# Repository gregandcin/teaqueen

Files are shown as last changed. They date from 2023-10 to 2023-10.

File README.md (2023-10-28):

# TeaQueen
An Alice Inspired Split Keyboard

## About the TeaQueen

The TeaQueen is a split, Alice keyboard running QMK firmware, with VIA and Vial compatibility (firmware to be realeased later). Based off of the [Red Queen](https://github.com/dbostian/redqueen) by [Dan Bostian](https://github.com/dbostian). 

V1 of the board, aka the Scuffed Edition, uses Kailh Hotswap sockets and Pro Micro compatitble dev boards, with a focus on [RP2040 Community Edition boards](https://docs.qmk.fm/#/platformdev_rp2040?id=rp2040_ce) such as the Elite-Pi.

## Why?

A PCB made by a factory is easier to assemble than handwiring.

## Want to make modifications?
This PCB uses the [Kiswitch](https://github.com/kiswitch/kiswitch) library as a globally installed pluggin in KiCad 7, so make sure to install that if you want to properly. Otherwise, everything is there for you as local libraries.

## Future Editions
A list of potential TODOs:

- [ ] Regular Solder socket boards
- [ ] An integrated RP2040 MCU
- [ ] A wireless edition

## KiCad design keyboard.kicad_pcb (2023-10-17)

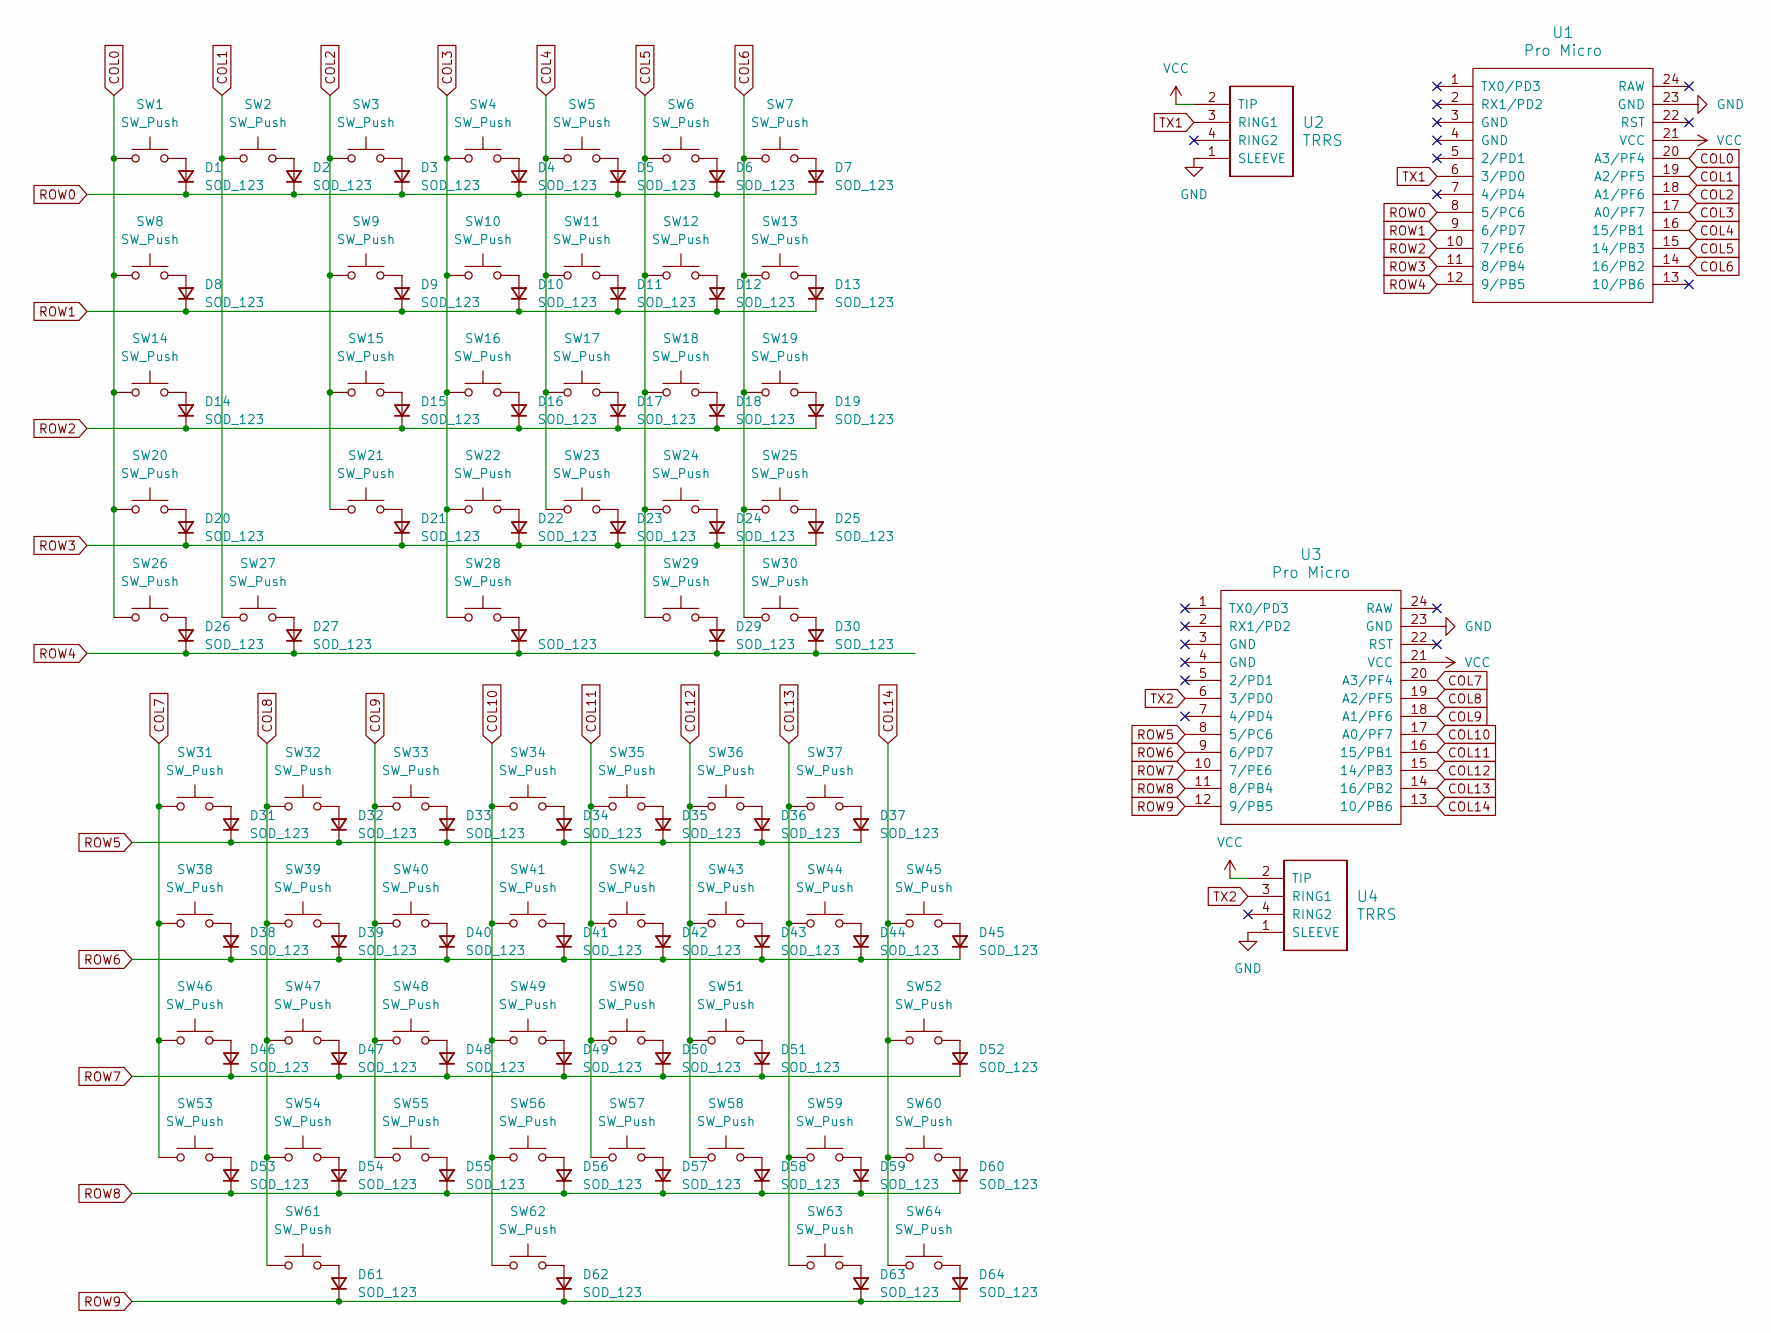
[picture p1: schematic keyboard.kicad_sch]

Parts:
D1, D2, D3, D4, D5, D6, D7, D8, D9, D10, D11, D12, D13, D14, D15, D16, D17, D18, D19, D20, D21, D22, D23, D24, D25, D26, D27, D28, D29, D30, D31, D32, D33, D34, D35, D36, D37, D38, D39, D40, D41, D42, D43, D44, D45, D46, D47, D48, D49, D50, D51, D52, D53, D54, D55, D56, D57, D58, D59, D60, D61, D62, D63, D64: SOD_123; D_SOD-123; MPN 1N914BWS; JLCPCB Part # C258181
SW1, SW2, SW3, SW4, SW5, SW6, SW7, SW9, SW10, SW11, SW12, SW13, SW15, SW16, SW17, SW18, SW19, SW21, SW22, SW23, SW24, SW25, SW27, SW30, SW31, SW32, SW33, SW34, SW35, SW36, SW38, SW39, SW40, SW41, SW42, SW43, SW44, SW46, SW47, SW48, SW49, SW50, SW51, SW53, SW54, SW55, SW56, SW57, SW58, SW60, SW63: SW_Push; SW_Hotswap_Kailh_MX_1.00u
SW8, SW26, SW28, SW45, SW62, SW64: SW_Push; SW_Hotswap_Kailh_MX_1.50u
SW14, SW59: SW_Push; SW_Hotswap_Kailh_MX_1.75u
SW20, SW52: SW_Push; SW_Hotswap_Kailh_MX_2.25u
SW29, SW37: SW_Push; SW_Hotswap_Kailh_MX_2.00u
SW61: SW_Push; SW_Hotswap_Kailh_MX_2.75u
U1, U3: Pro Micro; ArduinoProMicro
U2, U4: TRRS; TRRS-PJ-320A; MPN PJ-320A; JLCPCB Part # C2884926

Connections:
COL0: SW1.1, SW8.1, SW14.1, SW20.1, SW26.1, U1.20 (A3/PF4)
COL1: SW2.1, SW27.1, U1.19 (A2/PF5)
COL2: SW3.1, SW9.1, SW15.1, SW21.1, U1.18 (A1/PF6)
COL3: SW4.1, SW10.1, SW16.1, SW22.1, SW28.1, U1.17 (A0/PF7)
COL4: SW5.1, SW11.1, SW17.1, SW23.1, U1.16 (15/PB1)
COL5: SW6.1, SW12.1, SW18.1, SW24.1, SW29.1, U1.15 (14/PB3)
COL6: SW7.1, SW13.1, SW19.1, SW25.1, SW30.1, U1.14 (16/PB2)
COL7: SW31.1, SW38.1, SW46.1, SW53.1, U3.20 (A3/PF4)
COL8: SW32.1, SW39.1, SW47.1, SW54.1, SW61.1, U3.19 (A2/PF5)
COL9: SW33.1, SW40.1, SW48.1, SW55.1, U3.18 (A1/PF6)
COL10: SW34.1, SW41.1, SW49.1, SW56.1, SW62.1, U3.17 (A0/PF7)
COL11: SW35.1, SW42.1, SW50.1, SW57.1, U3.16 (15/PB1)
COL12: SW36.1, SW43.1, SW51.1, SW58.1, U3.15 (14/PB3)
COL13: SW37.1, SW44.1, SW59.1, SW63.1, U3.14 (16/PB2)
COL14: SW45.1, SW52.1, SW60.1, SW64.1, U3.13 (10/PB6)
GND: U1.23 (GND), U2.1 (SLEEVE), U3.23 (GND), U4.1 (SLEEVE)
unnamed: D1.2 (A), SW1.2
unnamed: D2.2 (A), SW2.2
unnamed: D3.2 (A), SW3.2
unnamed: D4.2 (A), SW4.2
unnamed: D5.2 (A), SW5.2
unnamed: D6.2 (A), SW6.2
unnamed: D7.2 (A), SW7.2
unnamed: D8.2 (A), SW8.2
unnamed: D9.2 (A), SW9.2
unnamed: D10.2 (A), SW10.2
unnamed: D11.2 (A), SW11.2
unnamed: D12.2 (A), SW12.2
unnamed: D13.2 (A), SW13.2
unnamed: D14.2 (A), SW14.2
unnamed: D15.2 (A), SW15.2
unnamed: D16.2 (A), SW16.2
unnamed: D17.2 (A), SW17.2
unnamed: D18.2 (A), SW18.2
unnamed: D19.2 (A), SW19.2
unnamed: D20.2 (A), SW20.2
unnamed: D21.2 (A), SW21.2
unnamed: D22.2 (A), SW22.2
unnamed: D23.2 (A), SW23.2
unnamed: D24.2 (A), SW24.2
unnamed: D25.2 (A), SW25.2
unnamed: D26.2 (A), SW26.2
unnamed: D27.2 (A), SW27.2
unnamed: D28.2 (A), SW28.2
unnamed: D29.2 (A), SW29.2
unnamed: D30.2 (A), SW30.2
unnamed: D31.2 (A), SW31.2
unnamed: D32.2 (A), SW32.2
unnamed: D33.2 (A), SW33.2
unnamed: D34.2 (A), SW34.2
unnamed: D35.2 (A), SW35.2
unnamed: D36.2 (A), SW36.2
unnamed: D37.2 (A), SW37.2
unnamed: D38.2 (A), SW38.2
unnamed: D39.2 (A), SW39.2
unnamed: D40.2 (A), SW40.2
unnamed: D41.2 (A), SW41.2
unnamed: D42.2 (A), SW42.2
unnamed: D43.2 (A), SW43.2
unnamed: D44.2 (A), SW44.2
unnamed: D45.2 (A), SW45.2
unnamed: D46.2 (A), SW46.2
unnamed: D47.2 (A), SW47.2
unnamed: D48.2 (A), SW48.2
unnamed: D49.2 (A), SW49.2
unnamed: D50.2 (A), SW50.2
unnamed: D51.2 (A), SW51.2
unnamed: D52.2 (A), SW52.2
unnamed: D53.2 (A), SW53.2
unnamed: D54.2 (A), SW54.2
unnamed: D55.2 (A), SW55.2
unnamed: D56.2 (A), SW56.2
unnamed: D57.2 (A), SW57.2
unnamed: D58.2 (A), SW58.2
unnamed: D59.2 (A), SW59.2
unnamed: D60.2 (A), SW60.2
unnamed: D61.2 (A), SW61.2
unnamed: D62.2 (A), SW62.2
unnamed: D63.2 (A), SW63.2
unnamed: D64.2 (A), SW64.2
ROW0: D1.1 (K), D2.1 (K), D3.1 (K), D4.1 (K), D5.1 (K), D6.1 (K), D7.1 (K), U1.8 (5/PC6)
ROW1: D8.1 (K), D9.1 (K), D10.1 (K), D11.1 (K), D12.1 (K), D13.1 (K), U1.9 (6/PD7)
ROW2: D14.1 (K), D15.1 (K), D16.1 (K), D17.1 (K), D18.1 (K), D19.1 (K), U1.10 (7/PE6)
ROW3: D20.1 (K), D21.1 (K), D22.1 (K), D23.1 (K), D24.1 (K), D25.1 (K), U1.11 (8/PB4)
ROW4: D26.1 (K), D27.1 (K), D28.1 (K), D29.1 (K), D30.1 (K), U1.12 (9/PB5)
ROW5: D31.1 (K), D32.1 (K), D33.1 (K), D34.1 (K), D35.1 (K), D36.1 (K), D37.1 (K), U3.8 (5/PC6)
ROW6: D38.1 (K), D39.1 (K), D40.1 (K), D41.1 (K), D42.1 (K), D43.1 (K), D44.1 (K), D45.1 (K), U3.9 (6/PD7)
ROW7: D46.1 (K), D47.1 (K), D48.1 (K), D49.1 (K), D50.1 (K), D51.1 (K), D52.1 (K), U3.10 (7/PE6)
ROW8: D53.1 (K), D54.1 (K), D55.1 (K), D56.1 (K), D57.1 (K), D58.1 (K), D59.1 (K), D60.1 (K), U3.11 (8/PB4)
ROW9: D61.1 (K), D62.1 (K), D63.1 (K), D64.1 (K), U3.12 (9/PB5)
TX1: U1.6 (3/PD0), U2.3 (RING1)
TX2: U3.6 (3/PD0), U4.3 (RING1)
VCC: U1.21 (VCC), U2.2 (TIP), U3.21 (VCC), U4.2 (TIP)

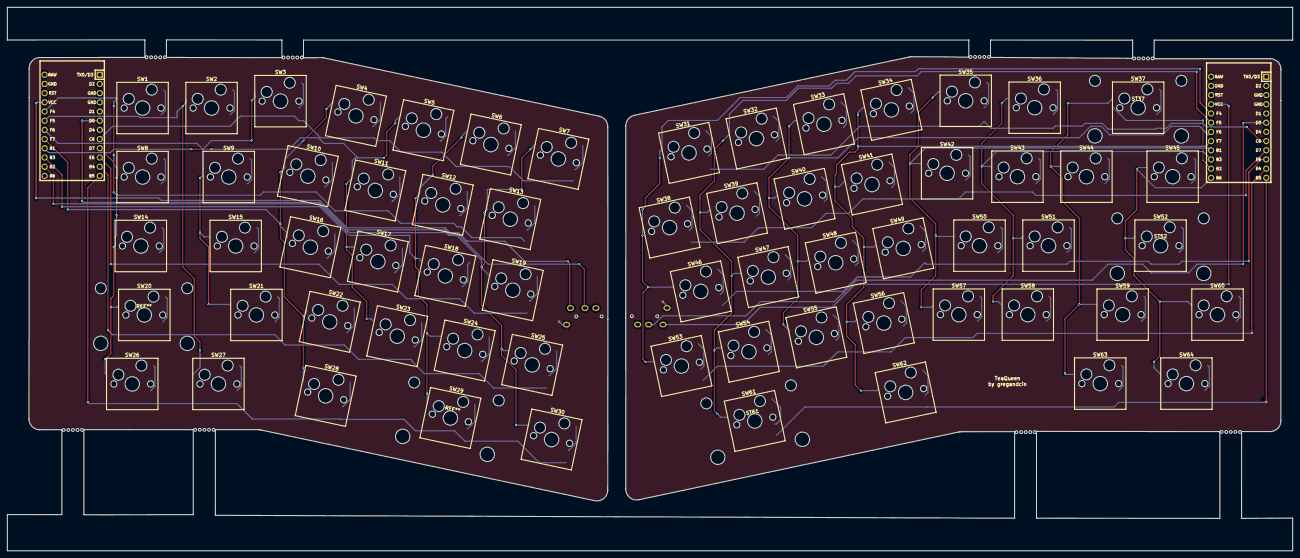
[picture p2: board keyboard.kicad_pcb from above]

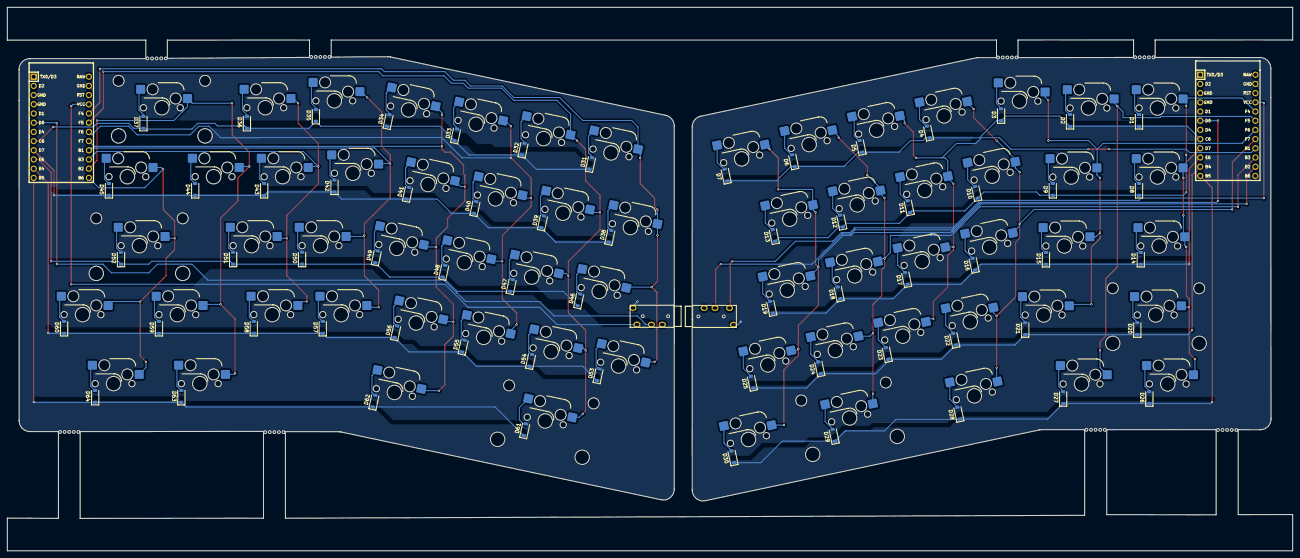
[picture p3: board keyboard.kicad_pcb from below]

Board: 2 copper layers, 355.0 x 150.1 mm, 135 parts (68 on the bottom side), 93 nets.

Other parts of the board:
ST37, ST52, ST61: MountingHole; Stabilizer_Cherry_MX_2.00u

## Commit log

2023-10-01 Remove second connection from TRRS and ProMicro, redo traces on PCB to be cleaner
    [keyboard.kicad_pcb, keyboard.kicad_sch]
2023-10-04 Redo edge cuts, panelize PCB edge cuts
    [keyboard.kicad_pcb]
2023-10-13 Add missing route
    [keyboard.kicad_pcb]
2023-10-13 Redo some of the panels
    [keyboard.kicad_pcb]
2023-10-13 Redo reouting to reduce number of vias
    [keyboard.kicad_pcb]
2023-10-13 Fix mousebite holes going further than pcb edge
    [keyboard.kicad_pcb]
2023-10-13 Move TRRS jacks around
    [keyboard.kicad_pcb]
2023-10-14 Clean up routes
    [keyboard.kicad_pcb]
2023-10-15 Add ground fill
    [keyboard.kicad_pcb]
2023-10-15 Redo edge cut corners
    [keyboard.kicad_pcb]
2023-10-15 Add JLCPCB part numbers
    [keyboard.kicad_pcb, keyboard.kicad_sch]
2023-10-15 Update Diode names
    [keyboard.kicad_pcb, keyboard.kicad_sch]
2023-10-17 Change from SOD_323F to SOD_123 footprint for diodes
    [keyboard.kicad_pcb, keyboard.kicad_sch]
